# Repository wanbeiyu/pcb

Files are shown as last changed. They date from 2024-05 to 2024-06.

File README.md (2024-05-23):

# PCB

## 3rd_party libraries

<table>
<tr><th>Part Number</th><th>Download Link</th></tr>
<tr><td>2171790001</td><td>

[ul_2171790001.zip](https://app.ultralibrarian.com/details/b6ea985d-a10c-11eb-9033-0a34d6323d74/Molex-Connector-Corporation/2171790001)

<dl>
<dt>Symbol</dt><dd>Normal View, 2171790001 1</dd>
<dt>Footprint</dt><dd>Basic View, 2171790001_MOL</dd>
<dt>Select Your CAD Format</dt><dd>3D CAD Model: STEP, KiCAD v6+</dd>
<dt>Symbol Pin Ordering</dt><dd>Sequential</dd>
<dt>Footprint Units</dt><dd>English (mil)</dd>
</dl>

フットプリントは作り直した。

</td></tr>
<tr><td>AD8403ARUZ1-REEL</td><td>

[LIB_AD8403ARUZ1-REEL.zip](https://componentsearchengine.com/part-view/AD8403ARUZ1-REEL/Analog%20Devices)

</td></tr>
<tr><td>ADG801BRTZ-REEL7</td><td>

[LIB_ADG801BRTZ-REEL7.zip](https://componentsearchengine.com/part-view/ADG801BRTZ-REEL7/Analog%20Devices)

</td></tr>
<tr><td>AWSCR-12.00CELA-C10-T3</td><td>

C33なら存在する。シンボルのプロパティから「値」「Manufacturer_Part_Number」を編集し、「データシート」「説明」「Mouser Part Number」「Mouser Price/Stock」「Arrow Part Number」「Arrow Price/Stock」の内容を削除の上、PCBA時にC10を指定する。

[LIB_AWSCR-12.00CELA-C33-T3.zip](https://componentsearchengine.com/part-view/AWSCR-12.00CELA-C33-T3/ABRACON)

</td></tr>
<tr><td>DS4424N+T&R</td><td>

[LIB_DS4424N+T&R.zip](https://componentsearchengine.com/part-view/DS4424N%2BT%26R/Analog%20Devices)

</td></tr>
<tr><td>MCP659-E_ML</td><td>

[LIB_MCP659-E_ML.zip](https://componentsearchengine.com/part-view/MCP659-E%2FML/Microchip)

</td></tr>
<tr><td>NCP167AMX330TBG</td><td>

[ul_NCP167AMX330TBG.zip](https://app.ultralibrarian.com/details/5d94e4bf-e68c-11ea-b55a-0a34d6323d74/onsemi/NCP167AMX330TBG)

<dl>
<dt>Symbol</dt><dd>Normal View, NCP167AMX330TBG 1</dd>
<dt>Footprint</dt><dd>Basic View, XDFN4_1X1_711AJ_ONS</dd>
<dt>Select Your CAD Format</dt><dd>KiCAD v6+</dd>
<dt>Symbol Pin Ordering</dt><dd>Sequential</dd>
<dt>Footprint Units</dt><dd>English (mil)</dd>
</dl>
</td></tr>
<tr><td>SK6805-EC15</td><td>

[LIB_SK6805-EC15.zip](https://componentsearchengine.com/part-view/SK6805-EC15/Shenzhen%20Normand%20Electronic)

</td></tr>
<tr><td>TC42X-2-102E</td><td>

[LIB_TC42X-2-102E.zip](https://componentsearchengine.com/part-view/TC42X-2-102E/Bourns)

</td></tr>
<tr><td>W25Q16JVUXIQ</td><td>

[LIB_W25Q16JVUXIQ.zip](https://componentsearchengine.com/part-view/W25Q16JVUXIQ/Winbond)

</td></tr>
<tr><td>XCL103D503CR-G</td><td>

[LIB_XCL103D503CR-G.zip](https://componentsearchengine.com/part-view/XCL103D503CR-G/Torex)

</td></tr>
</table>

## 部品選定メモ

### 電源

New 3DS LLには5V以上の電源を引き出せるTPはない（電源接続時4.38V、バッテリー駆動時3.92V、消耗時は3.1V程度まで低下）。5Vに昇圧→3.3Vに降圧する。

特にコイル一体型のICが実装面積が小さくなる。XCL103のI<sub>LIM</sub>で十分と判断した。

<table>
<tr>
<th>品番</th>
<th>詳細</th>
</tr>
<tr>
<td>XCL103D503CR-G</td>
<td>

- PWM/PFM自動切替制御
- Complete Output Disconnect
- Output Voltage: 5.0V
- I<sub>LIM</sub>: 1.3A

</td>
</tr>
<tr>
<td>XCL105A501H2-G</td>
<td>

- PWM/PFM制御
- Complete Output Disconnect
  - A・Dから選択で、Aしか在庫がない<br>https://www.digikey.jp/short/0qb0394h<br>https://mou.sr/4bJGSOZ
- Output Voltage: 5.0V
- I<sub>LIM</sub>: 2.42A

</td>
</tr>
</table>

以前はRaspberry Pi Debug Probeを参考に[AP2112K-3.3TRG1](https://www.digikey.jp/ja/products/detail/diodes-incorporated/AP2112K-3-3TRG1/4470746)を使用していた。

| 機能 | 値 |
| --- | --- |
| 出力構成 | ポジティブ |
| 出力タイプ | 固定 |
| 電圧 - 出力（最小/固定） | 3.3V |
| 電流 - 出力 | 600mA |

600mA以上出ていればどれでもよさそうだ。[NCP167AMX330TBG](https://www.digikey.jp/ja/products/detail/onsemi/NCP167AMX330TBG/9169759)が十分小さい。

### 発振回路

[AEL X12M000000S096](https://abracon.com/datasheets/AEL-Crystals/PN/X12M000000S096.pdf)が元の水晶[^1]。

[^1]: https://forums.raspberrypi.com/viewtopic.php?t=349741

- 12MHz
- ESR：50Ωに寄せる
- 内蔵コンデンサ
- セラミックタイプ

[検索結果](https://www.digikey.jp/short/p5qp35qr)

Operating Temperature（`CELA`は85度まで、`CELB`は125度まで）、静電容量（33pF／10pF）を選択する。以前の設計では10pFを用いたので、今回も10pF+1kΩ抵抗で使用する。

[AWSCR-12.00CELA-C10-T3](https://www.digikey.jp/short/t2mnvzrp)

## フルカラーLED

いわゆるNeoPixel、WS2812BとSK6812（12mA：たぶんより明るい）/SK6805（5mA）は同じものらしい[^2]。前者がオリジナル、後者がクローン。

[^2]: https://romly.com/blog/neopixel_variation/

SK6805-EC15が1.5mm角。

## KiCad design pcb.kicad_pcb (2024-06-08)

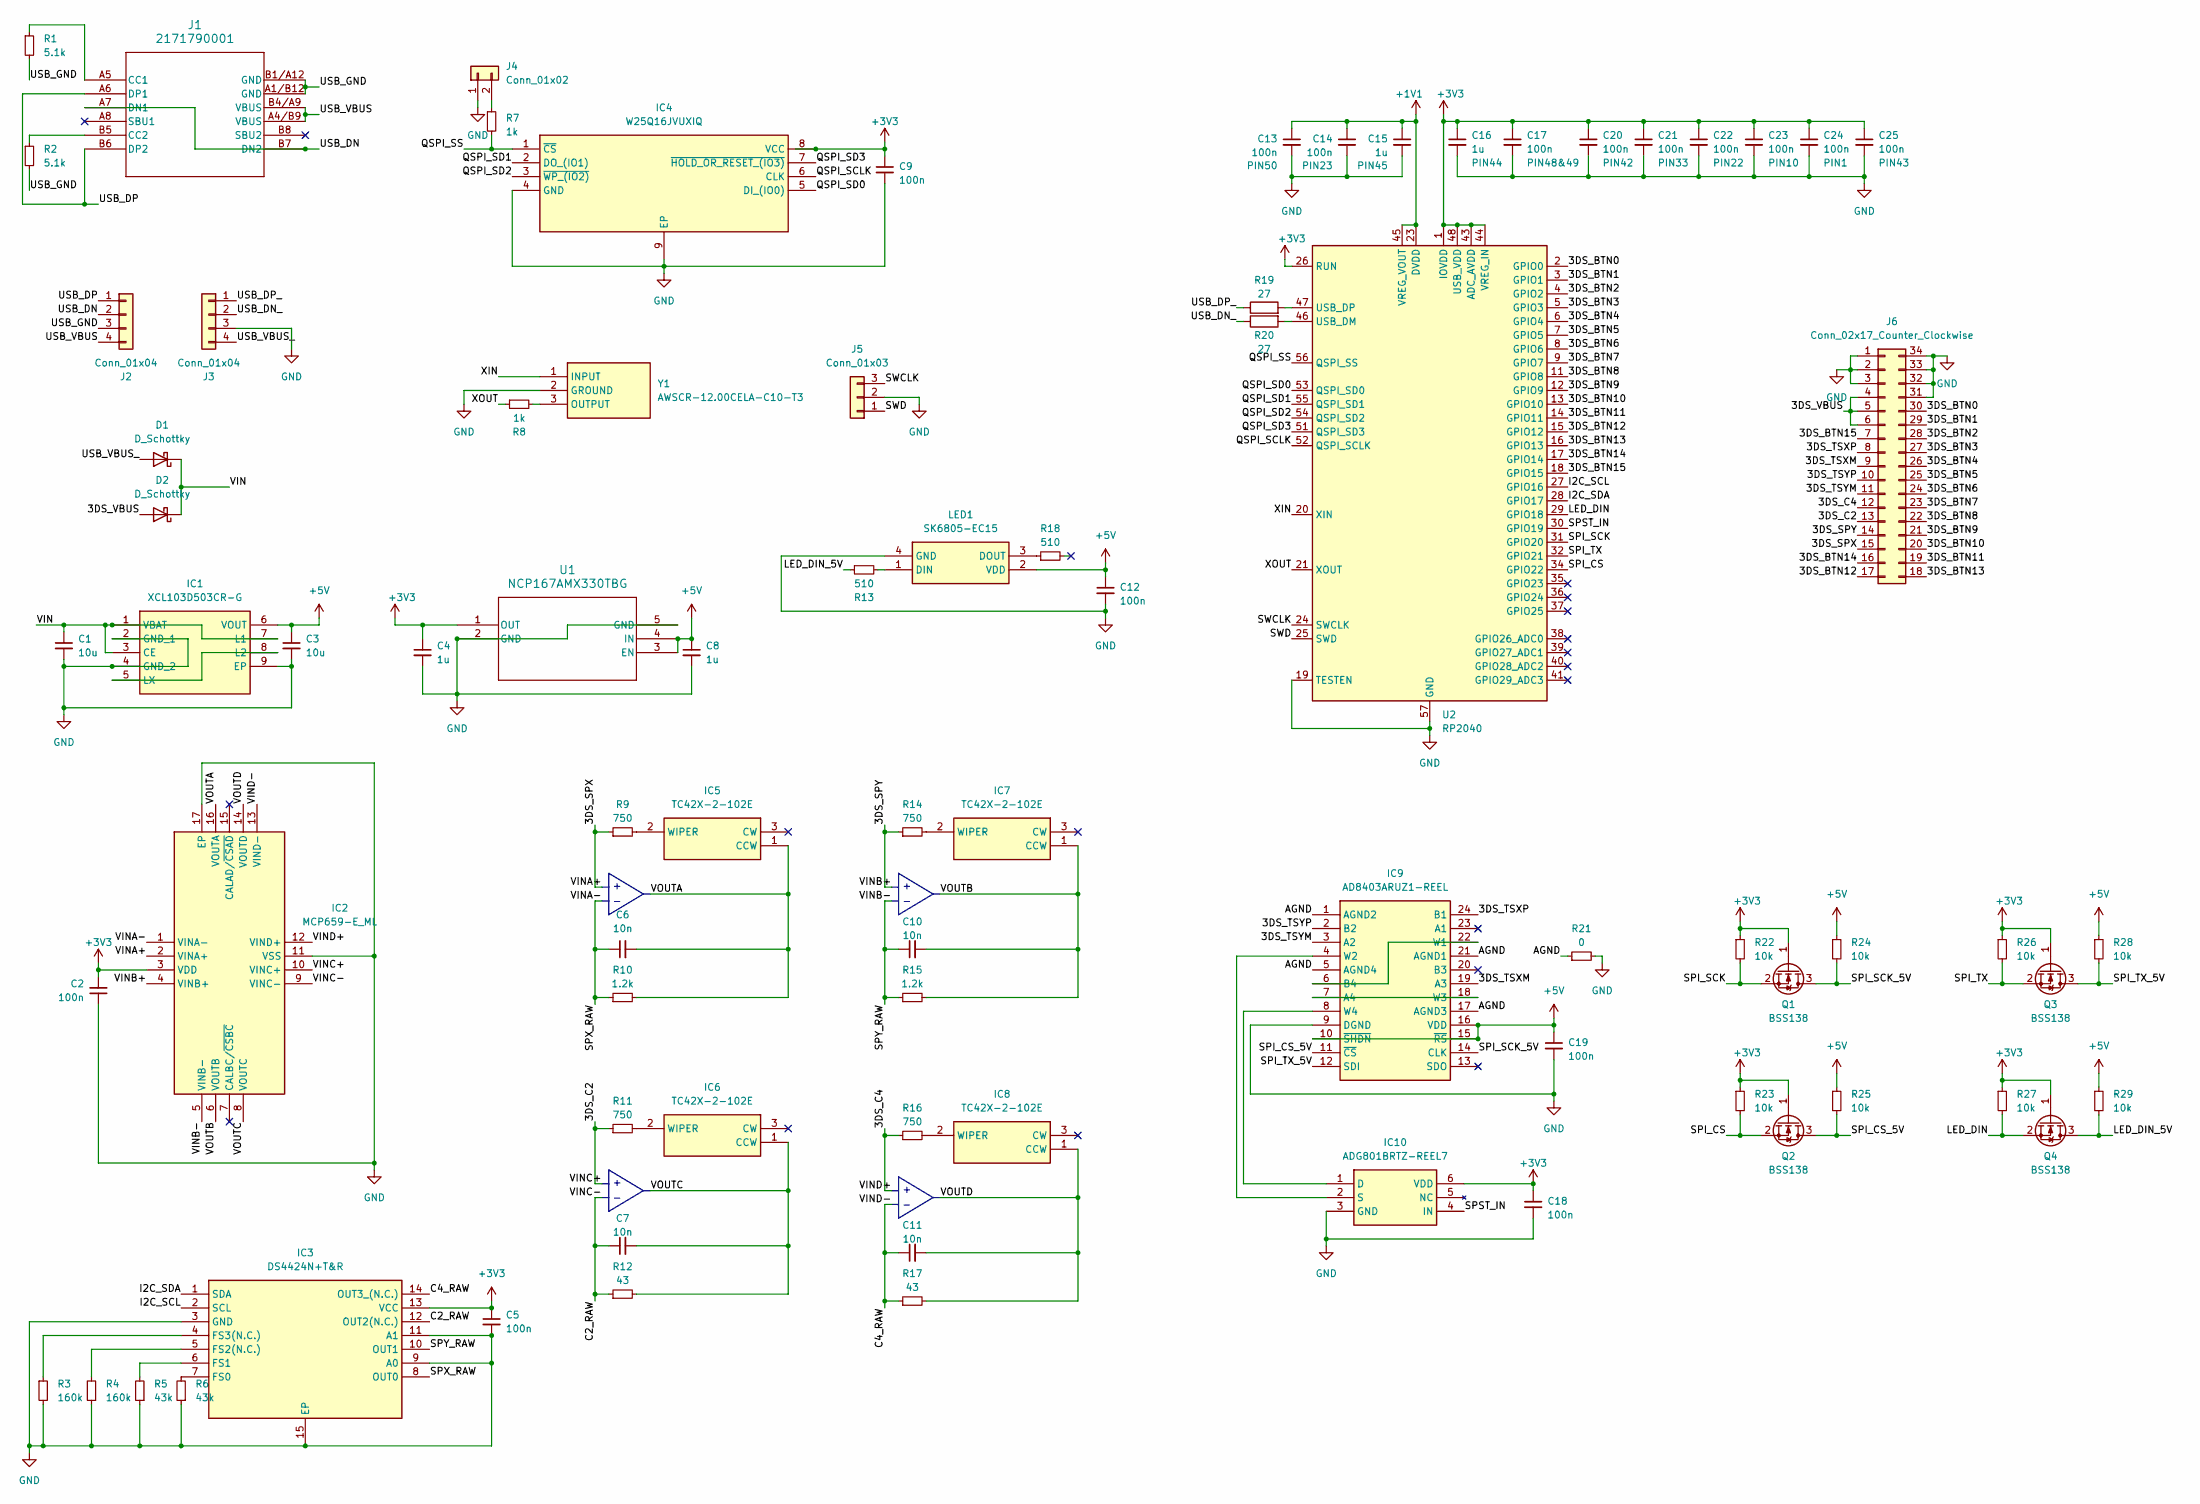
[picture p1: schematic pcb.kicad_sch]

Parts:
C1, C3: 10u; C_0603_1608Metric; Part TMK107BBJ106MA-T; LCSC C386081
C2, C5, C9, C12, C13, C14, C17, C18, C19, C20, C21, C22, C23, C24, C25: 100n; C_0201_0603Metric
C4, C8, C15, C16: 1u; C_0201_0603Metric
C6, C7, C10, C11: 10n; C_0201_0603Metric
D1, D2: D_Schottky; D_SOD-523
IC1: XCL103D503CR-G; XCL103D503CRG; Manufacturer_Part_Number XCL103D503CR-G; Mouser Part Number 865-XCL103D503CR-G
IC2: MCP659-E_ML; QFN65P400X400X100-17N-D; Manufacturer_Part_Number MCP659-E/ML
IC3: DS4424N+T&R; SON40P300X300X80-15N; Manufacturer_Part_Number DS4424N+T&R; Mouser Part Number 700-DS4424NT&R
IC4: W25Q16JVUXIQ; SON50P300X200X60-9N; Manufacturer_Part_Number W25Q16JVUXIQ
IC5, IC6, IC7, IC8: TC42X-2-102E; TC42X2102E; Manufacturer_Part_Number TC42X-2-102E; Mouser Part Number 652-TC42X-2-102E
IC9: AD8403ARUZ1-REEL; SOP65P640X120-24N; Manufacturer_Part_Number AD8403ARUZ1-REEL; Mouser Part Number 584-AD8403ARUZ1-R
IC10: ADG801BRTZ-REEL7; SOT95P280X145-6N; Manufacturer_Part_Number ADG801BRTZ-REEL7; Mouser Part Number 584-ADG801BRTZ-R7
J1: 2171790001
J2, J3: Conn_01x04; PinHeader_1x04_P1.27mm_Vertical
J4: Conn_01x02; PinHeader_1x02_P1.27mm_Vertical
J5: Conn_01x03; PinHeader_1x03_P1.27mm_Vertical
J6: Conn_02x17_Counter_Clockwise; 5055503020
LED1: SK6805-EC15; SK6805EC15; Manufacturer_Part_Number SK6805-EC15
Q1, Q2, Q3, Q4: BSS138; SOT-23
R1, R2: 5.1k; R_0201_0603Metric
R3, R4: 160k; R_0201_0603Metric
R5, R6: 43k; R_0201_0603Metric
R7, R8: 1k; R_0201_0603Metric
R9, R11, R14, R16: 750; R_0201_0603Metric
R10, R15: 1.2k; R_0201_0603Metric
R12, R17: 43; R_0201_0603Metric
R13, R18: 510; R_0201_0603Metric
R19, R20: 27; R_0201_0603Metric
R21: 0; R_0201_0603Metric
R22, R23, R24, R25, R26, R27, R28, R29: 10k; R_0201_0603Metric
U1: NCP167AMX330TBG; XDFN4_1X1_711AJ_ONS
U2: RP2040; QFN-56-1EP_7x7mm_P0.4mm_EP3.2x3.2mm
Y1: AWSCR-12.00CELA-C10-T3; AWSCR1200CELAC33T3; Manufacturer_Part_Number AWSCR-12.00CELA-C10-T3

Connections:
+1V1: C13.1, C14.1, C15.1, U2.23 (DVDD), U2.45 (VREG_VOUT), U2.50 (DVDD)
+3V3: C2.2, C4.1, C5.1, C9.1, C16.1, C17.1, C18.1, C20.1, C21.1, C22.1, C23.1, C24.1, C25.1, IC2.3 (VDD), IC3.13 (VCC), IC4.8 (VCC), IC10.6 (VDD), Q1.1 (G), Q2.1 (G), Q3.1 (G), Q4.1 (G), R22.1, R23.1, R26.1, R27.1, U1.1 (OUT), U2.1 (IOVDD), U2.10 (IOVDD), U2.22 (IOVDD), U2.26 (RUN), U2.33 (IOVDD), U2.42 (IOVDD), U2.43 (ADC_AVDD), U2.44 (VREG_IN), U2.48 (USB_VDD), U2.49 (IOVDD)
+5V: C3.1, C8.1, C12.1, C19.1, IC1.6 (VOUT), IC9.10 (~SHDN), IC9.15 (~RS), IC9.16 (VDD), LED1.2 (VDD), R24.1, R25.1, R28.1, R29.1, U1.3 (EN), U1.4 (IN)
/3DS_BTN0: J6.30, U2.2 (GPIO0)
/3DS_BTN1: J6.29, U2.3 (GPIO1)
/3DS_BTN2: J6.28, U2.4 (GPIO2)
/3DS_BTN3: J6.27, U2.5 (GPIO3)
/3DS_BTN4: J6.26, U2.6 (GPIO4)
/3DS_BTN5: J6.25, U2.7 (GPIO5)
/3DS_BTN6: J6.24, U2.8 (GPIO6)
/3DS_BTN7: J6.23, U2.9 (GPIO7)
/3DS_BTN8: J6.22, U2.11 (GPIO8)
/3DS_BTN9: J6.21, U2.12 (GPIO9)
/3DS_BTN10: J6.20, U2.13 (GPIO10)
/3DS_BTN11: J6.19, U2.14 (GPIO11)
/3DS_BTN12: J6.17, U2.15 (GPIO12)
/3DS_BTN13: J6.18, U2.16 (GPIO13)
/3DS_BTN14: J6.16, U2.17 (GPIO14)
/3DS_BTN15: J6.7, U2.18 (GPIO15)
/3DS_C2: IC2.10 (VINC+), J6.13, R11.1
/3DS_C4: IC2.12 (VIND+), J6.12, R16.1
/3DS_SPX: IC2.2 (VINA+), J6.15, R9.1
/3DS_SPY: IC2.4 (VINB+), J6.14, R14.1
/3DS_TSXM: IC9.19 (A3), J6.9
/3DS_TSXP: IC9.24 (B1), J6.8
/3DS_TSYM: IC9.3 (A2), J6.11
/3DS_TSYP: IC9.2 (B2), J6.10
/3DS_VBUS: D2.2 (A), J6.4, J6.5, J6.6
/AGND: IC9.1 (AGND2), IC9.5 (AGND4), IC9.17 (AGND3), IC9.21 (AGND1), R21.1
/C2_RAW: C7.1, IC2.9 (VINC-), IC3.12 (OUT2(N.C.)), R12.1
/C4_RAW: C11.1, IC2.13 (VIND-), IC3.14 (OUT3_(N.C.)), R17.1
/I2C_SCL: IC3.2 (SCL), U2.27 (GPIO16)
/I2C_SDA: IC3.1 (SDA), U2.28 (GPIO17)
/LED_DIN: Q4.2 (S), R27.2, U2.29 (GPIO18)
/LED_DIN_5V: Q4.3 (D), R13.1, R29.2
/QSPI_SCLK: IC4.6 (CLK), U2.52 (QSPI_SCLK)
/QSPI_SD0: IC4.5 (DI_(IO0)), U2.53 (QSPI_SD0)
/QSPI_SD1: IC4.2 (DO_(IO1)), U2.55 (QSPI_SD1)
/QSPI_SD2: IC4.3 (~WP_(IO2)), U2.54 (QSPI_SD2)
/QSPI_SD3: IC4.7 (~HOLD_OR_RESET_(IO3)), U2.51 (QSPI_SD3)
/QSPI_SS: IC4.1 (~CS), R7.2, U2.56 (QSPI_SS)
/SPI_CS: Q2.2 (S), R23.2, U2.34 (GPIO22)
/SPI_CS_5V: IC9.11 (~CS), Q2.3 (D), R25.2
/SPI_SCK: Q1.2 (S), R22.2, U2.31 (GPIO20)
/SPI_SCK_5V: IC9.14 (CLK), Q1.3 (D), R24.2
/SPI_TX: Q3.2 (S), R26.2, U2.32 (GPIO21)
/SPI_TX_5V: IC9.12 (SDI), Q3.3 (D), R28.2
/SPST_IN: IC10.4 (IN), U2.30 (GPIO19)
/SPX_RAW: C6.1, IC2.1 (VINA-), IC3.8 (OUT0), R10.1
/SPY_RAW: C10.1, IC2.5 (VINB-), IC3.10 (OUT1), R15.1
/SWCLK: J5.3, U2.24 (SWCLK)
/SWD: J5.1, U2.25 (SWD)
/USB_DN: J1.A7 (DN1), J1.B7 (DN2), J2.2
/USB_DN_: J3.2, R20.1
/USB_DP: J1.A6 (DP1), J1.B6 (DP2), J2.1
/USB_DP_: J3.1, R19.1
/USB_GND: J1.A1/B12 (GND), J1.B1/A12 (GND), J2.3, R1.2, R2.2
/USB_VBUS: J1.A4/B9 (VBUS), J1.B4/A9 (VBUS), J2.4
/USB_VBUS_: D1.2 (A), J3.4
/VIN: C1.1, D1.1 (K), D2.1 (K), IC1.1 (VBAT), IC1.3 (CE), IC1.7 (L1)
/VOUTA: C6.2, IC2.16 (VOUTA), IC5.1 (CCW), R10.2
/VOUTB: C10.2, IC2.6 (VOUTB), IC7.1 (CCW), R15.2
/VOUTC: C7.2, IC2.8 (VOUTC), IC6.1 (CCW), R12.2
/VOUTD: C11.2, IC2.14 (VOUTD), IC8.1 (CCW), R17.2
/XIN: U2.20 (XIN), Y1.1 (INPUT)
/XOUT: R8.1, U2.21 (XOUT)
GND: C1.2, C2.1, C3.2, C4.2, C5.2, C8.2, C9.2, C12.2, C13.2, C14.2, C15.2, C16.2, C17.2, C18.2, C19.2, C20.2, C21.2, C22.2, C23.2, C24.2, C25.2, IC1.2 (GND_1), IC1.4 (GND_2), IC1.9 (EP), IC2.11 (VSS), IC2.17 (EP), IC3.3 (GND), IC3.9 (A0), IC3.11 (A1), IC3.15 (EP), IC4.4 (GND), IC4.9 (EP), IC9.9 (DGND), IC10.3 (GND), J3.3, J4.1, J5.2, J6.1, J6.2, J6.3, J6.31, J6.32, J6.33, J6.34, LED1.4 (GND), R3.2, R4.1, R5.1, R6.1, R21.2, U1.2 (GND), U1.5 (GND), U2.19 (TESTEN), U2.57 (GND), Y1.2 (GROUND)
unnamed: IC1.5 (LX), IC1.8 (L2)
unnamed: IC3.7 (FS0), R6.2
unnamed: IC3.6 (FS1), R5.2
unnamed: IC3.5 (FS2(N.C.)), R4.2
unnamed: IC3.4 (FS3(N.C.)), R3.1
unnamed: IC5.2 (WIPER), R9.2
unnamed: IC6.2 (WIPER), R11.2
unnamed: IC7.2 (WIPER), R14.2
unnamed: IC8.2 (WIPER), R16.2
unnamed: IC9.7 (A4), IC9.18 (W3)
unnamed: IC9.6 (B4), IC9.22 (W1)
unnamed: IC9.8 (W4), IC10.1 (D)
unnamed: IC9.4 (W2), IC10.2 (S)
unnamed: J1.A5 (CC1), R1.1
unnamed: J1.B5 (CC2), R2.1
unnamed: J4.2, R7.1
unnamed: LED1.1 (DIN), R13.2
unnamed: LED1.3 (DOUT), R18.1
unnamed: R20.2, U2.46 (USB_DM)
unnamed: R19.2, U2.47 (USB_DP)
unnamed: R8.2, Y1.3 (OUTPUT)

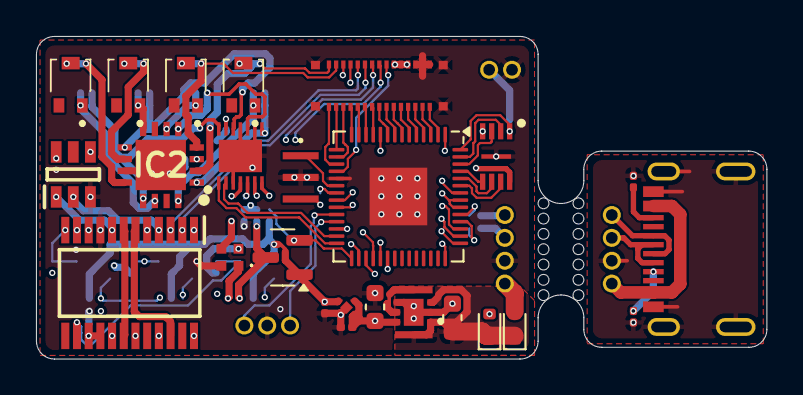
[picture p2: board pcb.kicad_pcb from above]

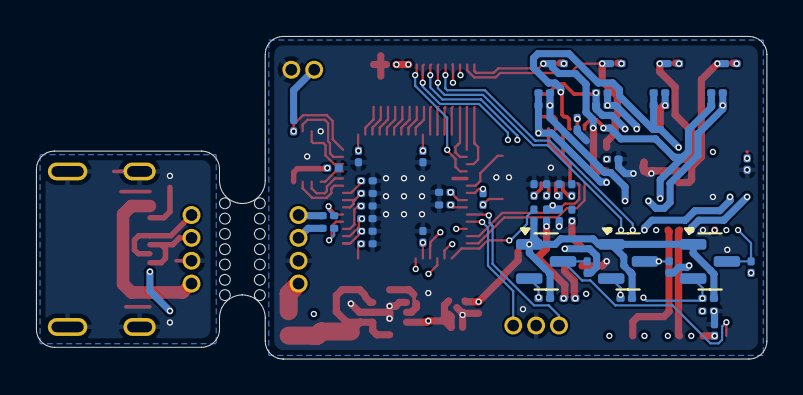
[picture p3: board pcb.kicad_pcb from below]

Board: 4 copper layers, 40.6 x 17.9 mm, 80 parts (51 on the bottom side), 88 nets.
